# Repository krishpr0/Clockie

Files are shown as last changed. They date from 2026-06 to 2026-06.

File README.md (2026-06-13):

[tableConvert.com_3jk98l.md](https://github.com/user-attachments/files/28841670/tableConvert.com_3jk98l.md)
# CLOCKIE 

Clockie, It is an Smart Bedside clock, It is an overall clock with all the necessary daily life data.
This project contains multiple sensors such as ambient light sensor, humditiy sensor, temperature sensor, buzzer, etc, and it also supports upto 2 speakers, which can be configurered as right and left.

zine

## What is this Project?
Clockie is an bed side smart clock that has the ability to also be controlled via a web broswer, why?
This unlocks the ability to change what the display is showing, according to what the user likes and also gives the ability to show notifictions, calls, etc also being able to add alarams.

- It contains a big 3.2 TFT display.
-  Also allows the user to insert SD Card to play what they like and also act as storage.
- Display auto adjust the brightness according to the surronding due to the protect the eyes T_T at night (*relatable*)
- Has a Led Matrix on the back for kwoolll light shows and also acts as a background light.

## How do we use clockie?
hmm

- THere are overall 3 buttons and a rotarty encoder and also a skude switch :)

    - The buttons are A, B, C respectively from left to the right when the display is facing toward you.
    - The encoder is on the most right side.
 
    - The Button A, is for START.
    - The Button B, is for STOP.
    - The Button C, is for RESET.
 
    - The Encoder acts as the scroll wheel which u can use to raom around the menu.
    - If you press the Encoder shaft the built-in switch will get activated and selectes an option from the menu which you currently are hovering onto.

That's all to the controls all other models wil be visible on the display.

## AHA Reason for building this
I needed an good alarm clock really really baddly beacuse we have classes from 5:45 am and its very strict soo havee to wake up sharp and reach there at 5:30 am. I would always wake up late lolll so I wanted to make this hoping it could help me.

Well starting from my everyday life, a normal alarm has been a hassel and a mess. First of all if u look at it at night the display would be soo freaking bright that the eyes woule evaporate. and also the display would be either too small or too big, The traditional alarm clock has always been boring, simple, and not fun; We would say alarm clock is just an alarm clock why make it advance? butt nahh we can make it morea advance to make our life easier.

and so yeah  the main reaons I built it wwas that i could wake up early in da mornig and also will be able to save my already bad eyes. YESz, also the time i wake up i could clearly see the time, weather, is it raning or not?, the temperature, etc. also set my notes and reminders for completeing task or anyting.
and also one of the biggest rason was beacuse of my friend, she wanted one really bad but couldnt get her hands on one.

## CAD



## Circuit Diagram:




### PCB


## PCB 3D 




[tableConvert.com_3jk98l.md](https://github.com/user-attachments/files/28841686/tableConvert.com_3jk98l.md)
| # | Designator | Footprint | Description | LCSC # | Qty | Unit Price (USD) | Unit Price (NPR) | Amount (NPR) | Link |
|---|---|---|---|---|-----|---|---|---|---|
| 1 | R12 | R0603 | 180Ω Resistor | C94599 | 1 | $1.2381 | ₹165.29 | ₹165.29 | https://www.lcsc.com/product-detail/C94599.html |
| 2 | BUZZER1 | BUZ-SMD_4P | 2.7kHz Buzzer MLT-8530 | C94599 | 1 | $0.2080 | ₹27.77 | ₹27.77 | https://www.lcsc.com/product-detail/C94599.html |
| 3 | C2,C3,C12,C26 | C0603 | 1uF Cap CL10A105KB8NNNC | C15849 | 4 | $0.0109 | ₹1.46 | ₹5.82 | https://www.lcsc.com/product-detail/C15849.html |
| 4 | C6,C15,C17,C19  | C0603 | 10uF Cap CL10A106MA8NRNC | C96446 | 4 | $0.0362 | ₹4.83 | ₹19.33 | https://www.lcsc.com/product-detail/C96446.html |
| 5 | C8 | C0603 | 22uF Cap CL10A226MP8NUNE | C86295 | 1 | $0.0211 | ₹2.82 | ₹2.82 | https://www.lcsc.com/product-detail/C86295.html |
| 6 | C1,C4,C5,...C27 | C0603 | 100nF Cap CC0603KRX7R9BB104 | C14663 | 17  | $0.0107 | ₹1.43 | ₹24.28 | https://www.lcsc.com/product-detail/C14663.html |
| 7 | P1,P2,P3,P4 | CONN-TH_2P | 5mm Terminal Block WJ301V | C8475 | 4 | $0.0917 | ₹12.24 | ₹48.97 | https://www.lcsc.com/product-detail/C8475.html |
| 8 | U4 | ESOP-8 | MSMP2307DN-LF-Z | C49375228 | 1 | $1.1372 | ₹151.82 | ₹151.82 | https://www.lcsc.com/product-detail/C49375228.html |
| 9 | F1 | F1812 | Polyfuse 2.6A SMD1812P260TF | C438899 | 1 | $0.1178 | ₹15.73 | ₹15.73 | https://www.lcsc.com/product-detail/C438899.html |
| 10 | L1 | IND-SMD | 4.7uH Inductor CKCS5040 | C354606 | 1 | $0.0503 | ₹6.72 | ₹6.72 | https://www.lcsc.com/product-detail/C354606.html |
| 11 | LCD2 | LCD-TH | 3.5"" ILI9488 LCD HS32B01A  | C19632786 | 1 | $8.3381 | ₹1,113.14 | ₹1,113.14 | https://www.lcsc.com/product-detail/C19632786.html |
| 12 | LED3-LED132 | LED-SMD_4P | SK6812MINI-B RGB LED | C5183448  | 127 | $0.0937 | ₹12.51 | ₹1,588.64 | https://www.lcsc.com/product-detail/C5183448.html  |
| 13 | LED2 | LED-SMD_4P | VEML7700-TR Light Sensor | C504893 | 1 | $0.7128 | ₹95.16 | ₹95.16 | https://www.lcsc.com/product-detail/C504893.html |
| 14 | LED1 | LED-SMD_L1.0 | NCD0402R1 Red LED | C130719 | 1 | $0.0386 | ₹5.15 | ₹5.15 | https://www.lcsc.com/product-detail/C130719.html |
| 15 | U1 | MIC-SMD_6P | ICS-43434 MEMS Mic | C5656610  | 1 | $6.5631 | ₹876.17 | ₹876.17 | https://www.lcsc.com/product-detail/C5656610.html  |
| 16 | U8 | QFN-24 | BQ25895RTWR USB-C Charger | C80200 | 1 | $2.0396 | ₹272.29 | ₹272.29 | https://www.lcsc.com/product-detail/C80200.html |
| 17 | R22 | R0402 | 33Ω Resistor RC0402FR | C138002 | 1 | $0.1000 | ₹13.35 | ₹13.35 | https://www.lcsc.com/product-detail/C138002.html |
| 18 | R11 | R0603 | 1kΩ Resistor RC0603FR | C22548 | 1 | $0.1800 | ₹24.03 | ₹24.03 | https://www.lcsc.com/product-detail/C22548.html |
| 19 | R24,R25 | R0603 | 2.2kΩ Resistor 0603WAF2201  | C4190 | 2 | $0.1500 | ₹20.02 | ₹40.05 | https://www.lcsc.com/product-detail/C4190.html |
| 20 | R2,R3 | R0603 | 5.1kΩ Resistor 0603WAF5101  | C23186 | 2 | $0.1600 | ₹21.36 | ₹42.72 | https://www.lcsc.com/product-detail/C23186.html |
| 21 | R8,R9,R10 | R0603 | 10kΩ Resistor 0603WAF1002 | C25804 | 3 | $0.1100 | ₹14.69 | ₹44.05 | https://www.lcsc.com/product-detail/C25804.html |
| 22 | R1,R13-R20,R26  | R0603 | 10kΩ Resistor RC0603FR | C98220 | 9 | $0.1800 | ₹24.03 | ₹216.27 | https://www.lcsc.com/product-detail/C98220.html |
| 23 | R6,R23 | R0603 | 100kΩ Resistor 0603WAF1003  | C25803 | 2 | $0.1800 | ₹24.03 | ₹48.06 | https://www.lcsc.com/product-detail/C25803.html |
| 24 | R5 | R0603 | 200kΩ Resistor 0603WAF2003  | C25811 | 1 | $0.1700 | ₹22.70 | ₹22.70 | https://www.lcsc.com/product-detail/C25811.html |
| 25 | R21 | R1206 | 100Ω Resistor CR1206F100R | C245445 | 1 | $0.0057 | ₹0.76 | ₹0.76 | https://www.lcsc.com/product-detail/C245445.html |
| 26 | S1 | SENSOR-SMD | HDC1080DMBR Temp/Humidity | C82227 | 1 | $1.4400 | ₹192.24 | ₹192.24 | https://www.lcsc.com/product-detail/C82227.html |
| 27 | U7 | SOIC-16 | DS3231SN RTC | C9866 | 1 | $5.3806 | ₹718.31 | ₹718.31 | https://www.lcsc.com/product-detail/C9866.html |
| 28 | SW5 | SW-SMD | SSAG230400 Rotary Encoder | C255506 | 1 | $0.3076 | ₹41.06 | ₹41.06 | https://www.lcsc.com/product-detail/C255506.html |
| 29 | SW2,SW3,SW4 | SW-TH | 1-1825027-4 Tactile Switch  | C2928195  | 3 | $0.1499 | ₹20.01 | ₹60.03 | https://www.lcsc.com/product-detail/C2928195.html  |
| 30 | U13 | SW-TH_CTR | ED0890DM Knob w/ Switch | C18213470 | 1 | $3.8268 | ₹510.88 | ₹510.88 | https://www.lcsc.com/product-detail/C18213470.html |
| 31 | CARD1 | TF-SMD | TF-01A MicroSD Socket | C91145 | 1 | $0.1922 | ₹25.66 | ₹25.66 | https://www.lcsc.com/product-detail/C91145.html |
| 32 | USB1 | USB-C-SMD | TYPE-C 16PIN 2MD Connector  | C2765186  | 1 | $0.0705 | ₹9.41 | ₹9.41 | https://www.lcsc.com/product-detail/C2765186.html  |
| 33 | U2 | VSSOP-10 | DRV2605LDGSR Haptic Driver  | C527464 | 1 | $1.2010 | ₹160.33 | ₹160.33 | https://www.lcsc.com/product-detail/C527464.html |
| 34 | U14 | MODULE | ESP32-S3-WROOM-1U-N16 | C2980298  | 1 | $5.6146 | ₹749.55 | ₹749.55 | https://www.lcsc.com/product-detail/C2980298.html  |
| 35 | U6,U12 | WLP-9 | MAX98357AEWL+T I2S Amp | C2682619  | 2 | $0.4656 | ₹62.16 | ₹124.32 | https://www.lcsc.com/product-detail/C2682619.html  |
| 36 | U3 | WSOF-6 | BH1750FVI-TR Lux Sensor | C78960 | 1 | $0.9329 | ₹124.54 | ₹124.54 | https://www.lcsc.com/product-detail/C78960.html |
| TOTAL | | | | | 203 | | | ₹7,587.41 | |

## How to Build


### What you need
- Soldering iron (fine tip recommended)
- Solder wire 
- Flux
- Multimeter
- USB-C cable

### Assembly order
1. Solder all SMD passives first (resistors, capacitors)
2. Solder ICs — BQ25895, MP2307, DS3231, HDC1080, BH1750, DRV2605, MAX98357 ×2
3. Solder ESP32-S3-WROOM-1U module
4. Solder USB-C connector and test 5V rail with multimeter before connecting anything else
5. Solder connectors — terminal blocks, SD card slot
6. Solder through-hole components — buttons, encoder
7. Connect LiPo battery via JST connector
8. Connect display via HDR-1X9 header
9. Solder SK6812 LED matrix on back side
10. Flash firmware via USB-C using PlatformIO
11. Open Serial Monitor — verify WiFi connects and sensors respond
12. Access web UI at the IP shown in Serial Monitor

### Firmware setup
- Install PlatformIO in VS Code
- Clone this repo
- Edit `firmware/src/config.h` — add your WiFi SSID, password, and OpenWeatherMap API key
- Run `pio run --target upload`

## GPIO Pinout
| GPIO | Function |
|---|---|
| IO4  | Reset button |
| IO5  | Encoder SW |
| IO6  | Encoder A |
| IO7  | Encoder B |
| IO8  | I2C SDA |
| IO9  | I2C SCL |
| IO10 | TFT CS |
| IO11 | SPI MOSI |
| IO12 | SPI SCK |
| IO13 | SPI MISO |
| IO14 | TFT RS/DC |
| IO15 | I2S LRCLK |
| IO16 | I2S BCLK |
| IO17 | I2S DIN |
| IO18 | Buzzer |
| IO19 | USB D- |
| IO20 | USB D+ |
| IO35 | LED matrix data |
| IO36 | Haptic trigger |
| IO37 | HOME button |
| IO38 | BACK button |
| IO39 | EXTRA button |
| IO45 | Mic SD |
| IO46 | SD card CS |
| IO47 | Mic SCK |
| IO48 | Mic WS |

# Feature
- Wifi & BLE capabilities
- 3 buttons & enconder
- 3.2 inch TFT display
- ESP32-S3**
- Temperature & Humiditiy sensor
- Ambient light sensor
- Haptic feedback
- Supports 2 speakers
- LED Matrix
- RTC
- BMS and charger
- Prayer times (Aladhan API)
- Google Calendar integration
- Pomodoro timer
- Web browser control
- Microphone
- MicroSD audio playback
- Auto brightness (BH1750 ambient light sensor)
- USB-C charging
- Backup battery (LiPo)

# Hardware
| Component | Part |
|---|---|
| MCU | ESP32-S3-WROOM-1U-N16 |
| Display | 3.2" ST7789 TFT HS32B01A |
| Charger IC | BQ25895RTWR |
| Buck converter | MSMP2307DN |
| Audio amp | MAX98357AEWL+T ×2 (stereo) |
| RTC | DS3231SN |
| Temp/Humidity | HDC1080DMBR |
| Light sensor | BH1750FVI-TR |
| Haptic driver | DRV2605LDGSR |
| Microphone | ICS-43434 |
| LED matrix | SK6812MINI-B ×127 |
| Encoder | EC11E18244A5 |
| Buttons | 1-1825027-4 ×3 |
| MicroSD | TF-01A |
| USB-C | TYPE-C 16PIN 2MD |
| PCB | Custom 2-layer JLCPCB |
| Case | 3D printed PETG |

## Web Interface
Once powered on and connected to WiFi, open a browser on any device 
on the same network and go to the IP address shown on the display.

From the web interface you can:
- Add and remove alarms
- Control LED matrix mode and color
- Start/stop Pomodoro timer
- Adjust display brightness
- View current weather and prayer times

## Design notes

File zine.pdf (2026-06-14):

the smart clock. cclloocckkiiee,,

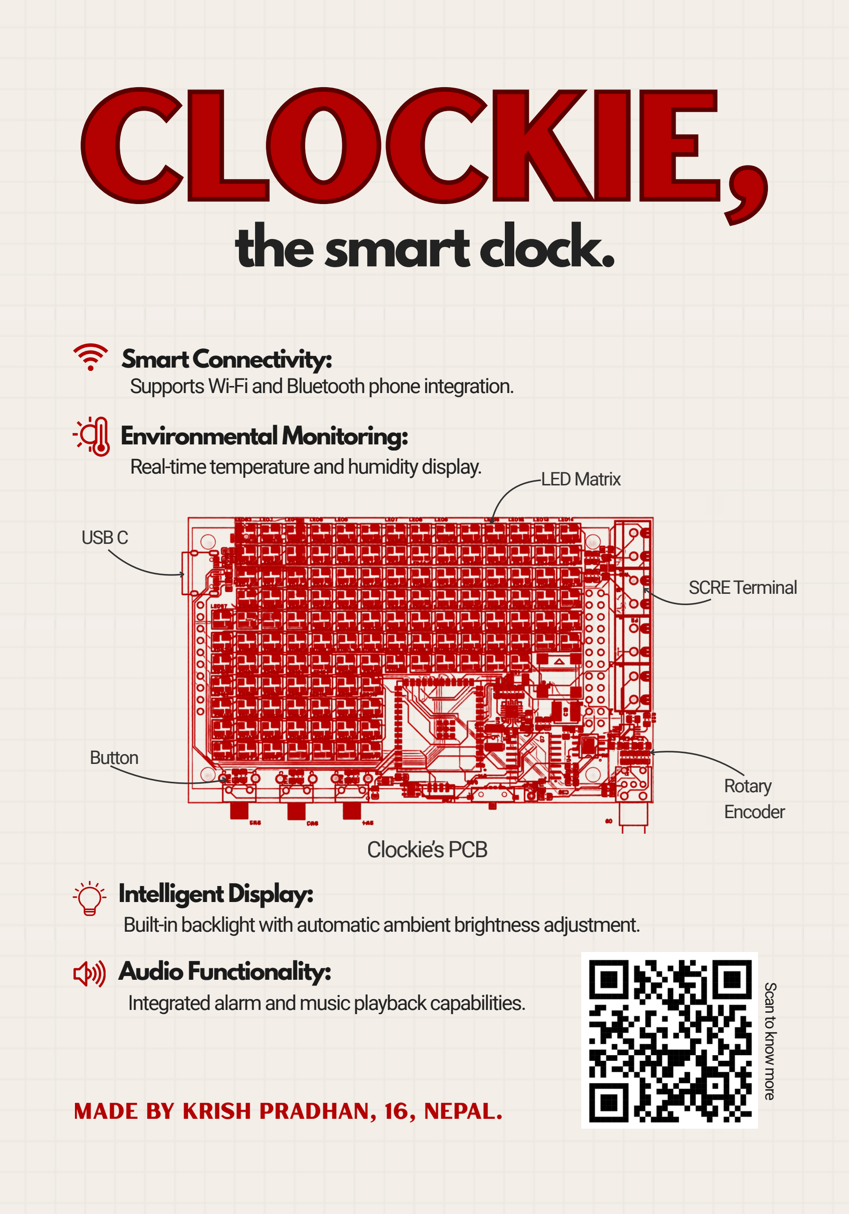
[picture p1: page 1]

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
Clockie’sPCB

SupportsWi-Fi andBluetoothphone integration.

SmartConnectivity:

Environmental Monitoring:

Intelligent Display:

AudioFunctionality:

Real-time temperature andhumiditydisplay.

Built-inbacklightwith automatic ambientbrightness adjustment.

Integratedalarmandmusicplayback capabilities.

Made by Krish Pradhan, 16, Nepal.

USBC

LEDMatrix

SCRETerminal

Rotary
Encoder

Button

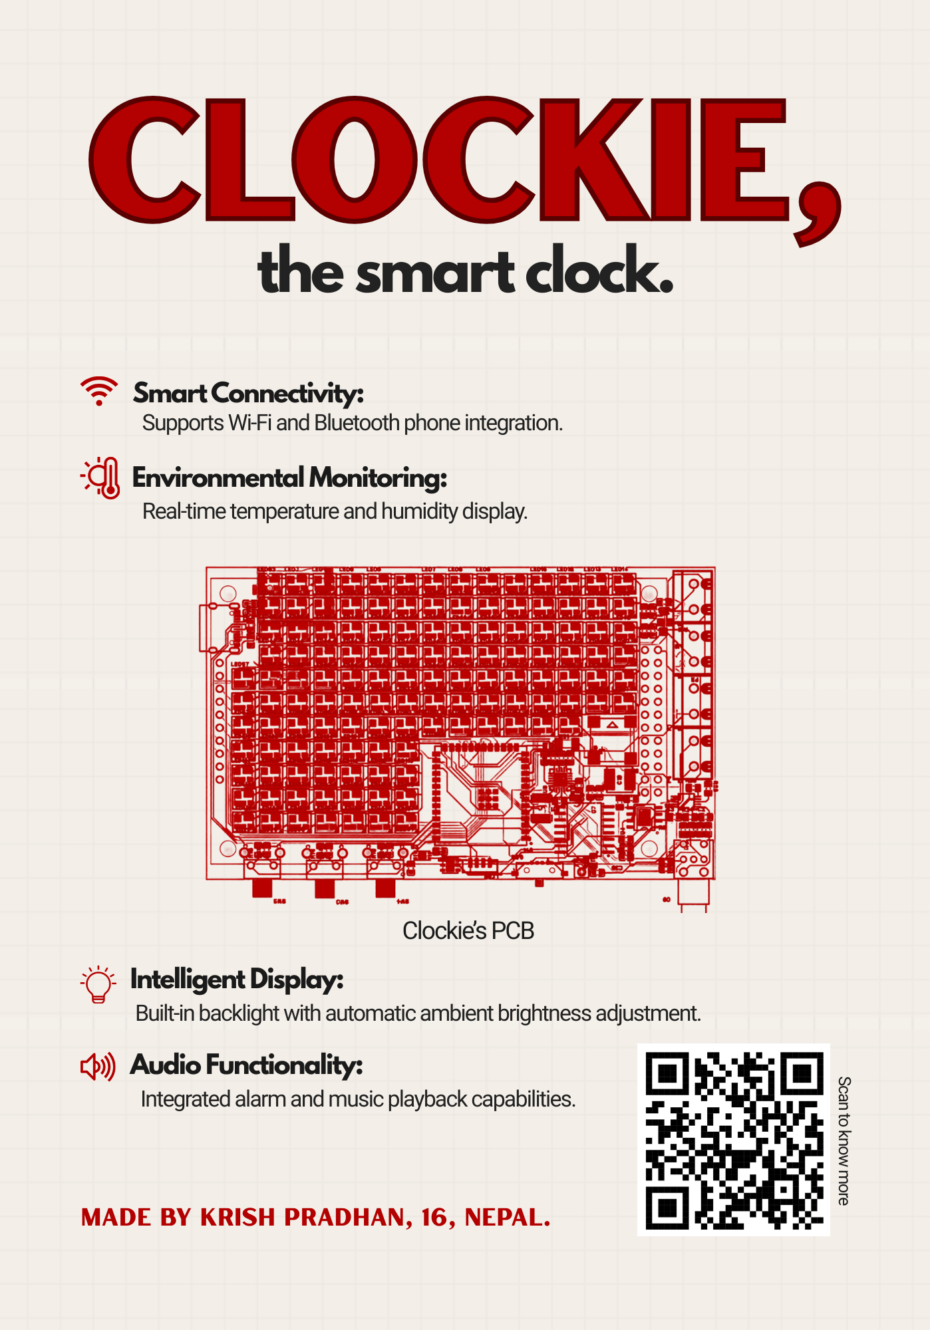
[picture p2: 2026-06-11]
zine.png

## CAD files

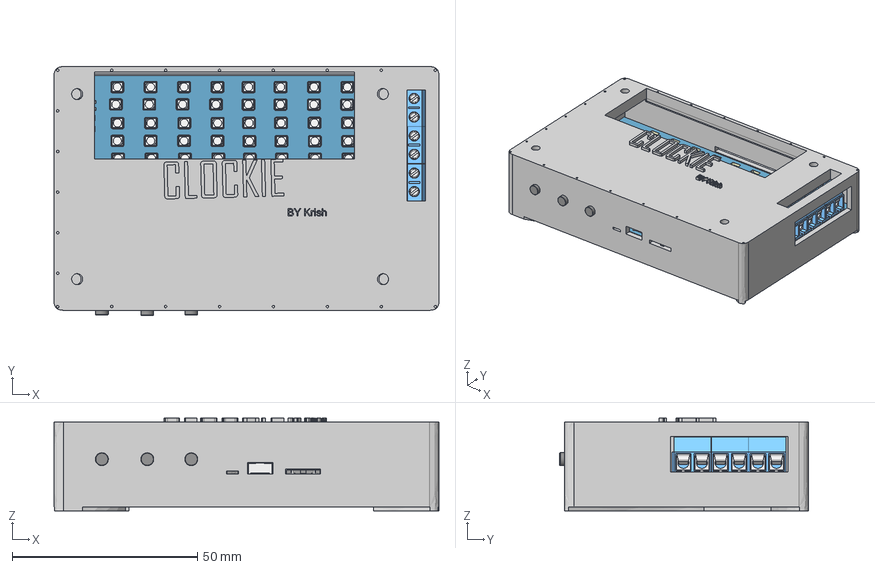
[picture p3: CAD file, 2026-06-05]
CAD/Clockie.step
104.0 x 67.2 x 25.0 mm
Board~MeGX
TopCopper~MeGX
BottomCopper~MeGX
TopFpcStiffener~MeGX
BottomFpcStiffener~MeGX
C0603~C0603_L1.6-W0.8-H0.8~MeGX x 21
CONN-TH_2P-P5.00_WJ301V-5.00-2P~CONN-TH_2P-P5.00_WJ301V-5.00-2P~MeGX x 3
R0603~R0603~MeGX x 18
F1812~F1812_L4.5-W3.2-H1.0~MeGX
LED0402-RD_YELLOW~LED0402-RD_YELLOW~MeGX
IND-SMD_L5.0-W5.0~IND-SMD_L5.0-W5.0-H2.1~MeGX
QFN-24_L4.0-W4.0-P0.50-TL-EP2.7~QFN-24_L4.0-W4.0-P0.50-TL-EP2.7~MeGX
SW-TH_1-1825027-4~SW-TH_1-1825027-4~MeGX x 3
ESOP-8_L4.9-W3.9-P1.27-LS6.0-BL-EP~ESOP-8_L4.9-W3.9-H1.6-LS6.0-P1.27~ MeGX
BUZ-SMD_4P-L8.5-W8.5-P8.50-BR~BUZ-SMD_4P-L8.5-W8.5-H3.0~MeGX
SW-SMD_SSAG230400~SW-SMD_SSAG230400~MeGX
USB-C-SMD_TYPE-C-16PIN-2MD-073~USB-C-SMD_TYPE-C-6PIN-2MD-073~MeGX
LED-SMD_4P-L6.8-W2.4_VEML7700-TR~LED-SMD_4P-L6.8-W2.4_VEML7700-TR~MeG X
SOIC-16_L10.3-W7.5-P1.27-LS10.3-BL~SOIC-16_L10.3-W7.5-H2.7-LS10.3-P1. 27~MeGX
LED-SMD_4P-L3.2-W2.8-LS5.9_SK6812MINI-E~LED-SMD_4P-L3.2-W2.8-LS5.9_SK 6812MINI-E~MeGX x 40
SENSOR-SMD_HDC1080DMBR~SENSOR-SMD_L3.0-W3.0-H0.8-P1.0~MeGX
WLP-9_L1.4-W1.3-P0.40-R3-C3-BR~WLP-9_L1.4-W1.3-P0.40-R3-C3-BR~MeGX x 2
WIRELM-SMD_ESP32-S3-WROOM-1U~WIRELM-SMD_ESP32-S3-WROOM-1U~MeGX
LCD-TH_L89.4-W56.0_HS32B01A~LCD-TH_L89.4-W56.0_HS32B01A~MeGX

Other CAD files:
CAD/Clockie.3mf
CAD/Clockie.f3z

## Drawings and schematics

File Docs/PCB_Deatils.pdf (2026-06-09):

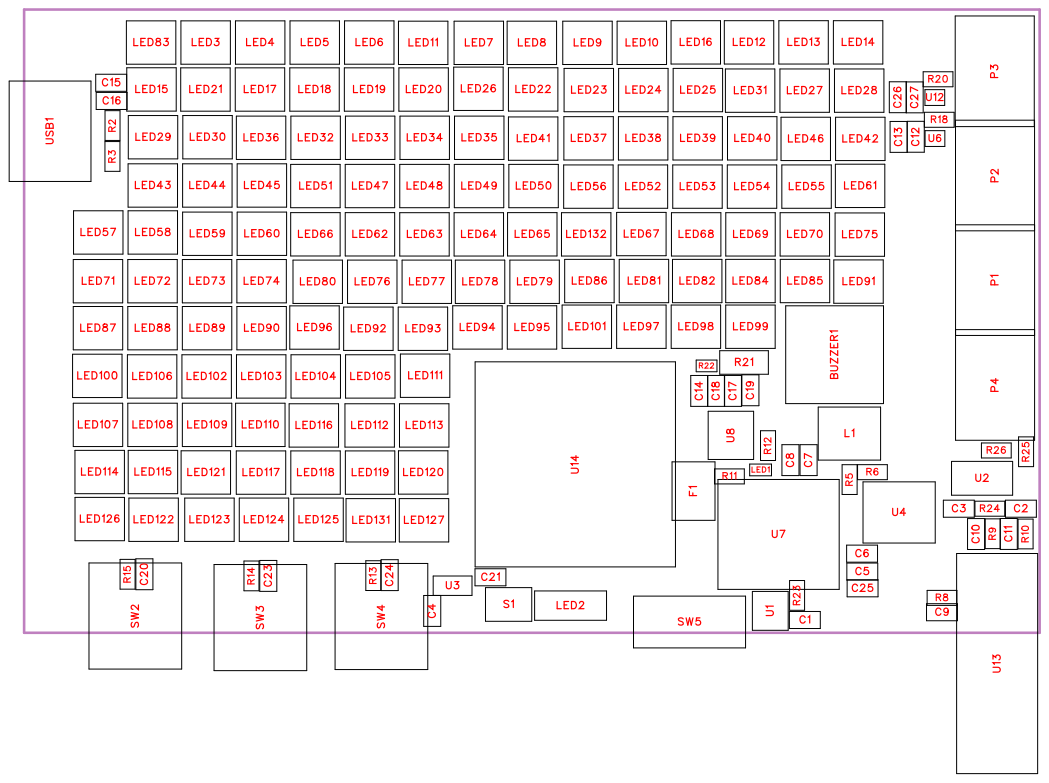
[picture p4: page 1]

LED83 | LED3 | LED4 | LED5 | LED6 | LED11 | LED7 | LED8 | LED9 | LED10 | LED16 | LED12 | LED13 | LED14

C15 | LED15 | LED21 | LED17 | LED18 | LED19 | LED20 | LED26 | LED22 | LED23 | LED24 | LED25 | LED31 | LED27 | LED28 | R20
C16 | | | | | | | | | | | | | | | | U12
LED29 | | LED30 | LED36 | LED32 | LED33 | LED34 | LED35 | LED41 | LED37 | LED38 | LED39 | LED40 | LED46 | LED42 | | R18

LED43 | LED44 | LED45 | LED51 | LED47 | LED48 | LED49 | LED50 | LED56 | LED52 | LED53 | LED54 | LED55 | LED61

LED57 | LED58 | LED59 | LED60 | LED66 | LED62 | LED63 | LED64 | LED65 | LED132 | LED67 | LED68 | LED69 | LED70 | LED75

LED71 | LED72 | LED73 | LED74 | LED80 | LED76 | LED77 | LED78 | LED79 | LED86 | LED81 | LED82 | LED84 | LED85 | LED91

LED87 | LED88 | LED89 | LED90 | LED96 | LED92 | LED93 | LED94 | LED95 | LED101 | LED97 | LED98 | LED99

LED100 | LED106 | LED102 | LED103 | LED104 | LED105 | LED111 | | | R22 | R21

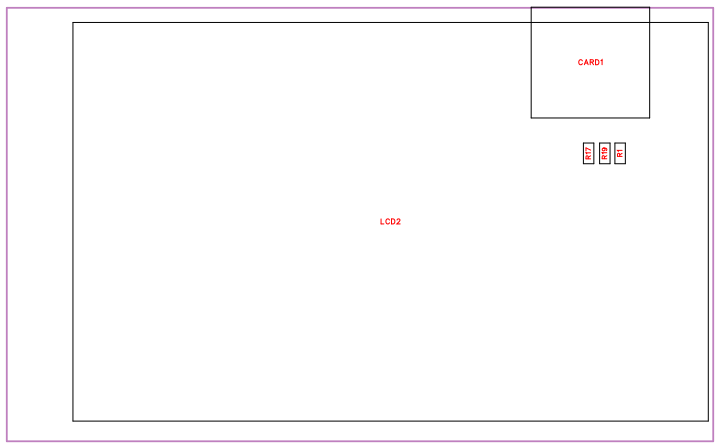
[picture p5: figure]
CARD1; LCD2

No. | Quantity | Designator | Footprint | Value | Manufacturer Part | Supplier Part | LCSC Price
1 | 1 | BUZZER1 | BUZ-SMD_4 P-L8.5-W8.5-P8.50-BR | 2.7kHz | MLT-8530 | C94599
2 | 17 | C1,C4,C5,C7,C9,C10,C11, C13,C14,C16,C18,C20,C21 ,C23,C24,C25,C27 | C0603 | 100nF | CC0603KRX 7R9BB104 | C14663
3 | 4 | C2,C3,C12,C26 | C0603 | 1uF | CL10A105KB 8NNNC | C15849
4 | 4 | C6,C15,C17,C19 | C0603 | 10uF | CL10A106M A8NRNC | C96446
5 | 1 | C8 | C0603 | 22uF | CL10A226M P8NUNE | C86295
6 | 1 | CARD1 | TF-SMD_TF-01A | | TF-01A | C91145
7 | 1 | F1 | F1812 | | SMD1812P2 60TF/16 | C438899
8 | 1 | L1 | IND-SMD_L5 .0-W5.0 | 4.7uH | CKCS5040-4 .7uH/M | C354606
9 | 1 | LCD2 | LCD-TH_L89 .4-W56.0_HS 32B01A | | HS32B01A | C19632786
10 | 1 | LED1 | LED-SMD_L 1.0-W0.5_FC -F1005UGK | | NCD0402R1 | C130719
11 | 1 | LED2 | LED-SMD_4 P-L6.8-W2.4 _VEML7700-TR | | VEML7700-T R | C504893

12 | 127 | LED3,LED4,LED5,LED6,LE D7,LED8,LED9,LED10,LED 11,LED12,LED13,LED14,LE D15,LED16,LED17,LED18, LED19,LED20,LED21,LED2 2,LED23,LED24,LED25,LE D26,LED27,LED28,LED29, LED30,LED31,LED32,LED3 3,LED34,LED35,LED36,LE D37,LED38,LED39,LED40, LED41,LED42,LED43,LED4 4,LED45,LED46,LED47,LE D48,LED49,LED50,LED51, LED52,LED53,LED54,LED5 5,LED56,LED57,LED58,LE D59,LED60,LED61,LED62, LED63,LED64,LED65,LED6 6,LED67,LED68,LED69,LE D70,LED71,LED72,LED73, LED74,LED75,LED76,LED7 7,LED78,LED79,LED80,LE D81,LED82,LED83,LED84, LED85,LED86,LED87,LED8 8,LED89,LED90,LED91,LE D92,LED93,LED94,LED95, LED96,LED97,LED98,LED9 9,LED100,LED101,LED102, LED103,LED104,LED105,L ED106,LED107,LED108,LE D109,LED110,LED111,LED 112,LED113,LED114,LED1 15,LED116,LED117,LED11 8,LED119,LED120,LED121, LED122,LED123,LED124,L ED125,LED126,LED127,LE D131,LED132

LED-SMD_4
P-L3.5-W3.5-
R-SK6812MI
NI

SK6812MINI-B-012

C5183448

13 | 4 | P1,P2,P3,P4 | CONN-TH_2 P-P5.00_WJ 301V-5.00-2 P | | WJ301V-5.0-02P-12-00A | C8475
14 | 9 | R1,R13,R14,R15,R17,R18, R19,R20,R26 | R0603 | 10k | RC0603FR-0 710KL | C98220
15 | 2 | R2,R3 | R0603 | 5.1k | 0603WAF51 01T5E | C23186
16 | 1 | R5 | R0603 | 200k | 0603WAF20 03T5E | C25811
17 | 2 | R6,R23 | R0603 | 100k | 0603WAF10 03T5E | C25803
18 | 3 | R8,R9,R10 | R0603 | 10k | 0603WAF10 02T5E | C25804
19 | 1 | R11 | R0603 | 1k | RC0603FR-0 71KL | C22548
20 | 1 | R12 | R0603 | 180 | | | 0.1759
21 | 1 | R21 | R1206 | 100 | CR1206F100 RP05Z | C245445

22 | 1 | R22 | R0402 | 33 | RC0402FR-0 733RL | C138002
23 | 2 | R24,R25 | R0603 | 2.2k | 0603WAF22 01T5E | C4190
24 | 1 | S1 | SENSOR-SM D_HDC1080 DMBR | | HDC1080DM BR | C82227
25 | 3 | SW2,SW3,SW4 | SW-TH_1-18 25027-4 | | 1-1825027-4 | C2928195
26 | 1 | SW5 | SW-SMD_SS AG230400 | | SSAG23040 0 | C255506
27 | 1 | U1 | MIC-SMD_6 P-L3.5-W2.7-P0.90-BL | | ICS-43434 | C5656610
28 | 1 | U2 | VSSOP-10_L 3.0-W3.0-P0. 50-LS4.9-BL | | DRV2605LD GSR | C527464
29 | 1 | U3 | WSOF-6_L2. 6-W1.6-P0.5 0-TL-EP | | BH1750FVI-TR | C78960
30 | 1 | U4 | ESOP-8_L4. 9-W3.9-P1.2 7-LS6.0-BL-E P | | MSMP2307D N-LF-Z | C49375228
31 | 2 | U6,U12 | WLP-9_L1.4-W1.3-P0.40-R3-C3-BR | | MAX98357A EWL+T | C2682619
32 | 1 | U7 | SOIC-16_L1 0.3-W7.5-P1. 27-LS10.3-B L | | DS3231SN# T&R | C9866
33 | 1 | U8 | QFN-24_L4.0 -W4.0-P0.50-TL-EP2.7 | | BQ25895RT WR | C80200
34 | 1 | U13 | SW-TH_CTR _ED0890DM-FE13.8S5.8-C10-2030 | | ED0890DM-FE13.8S5.8-C10-2030 | C18213470
35 | 1 | U14 | WIRELM-SM D_ESP32-S3 -WROOM-1U | 2.4GHz | ESP32-S3-W ROOM-1U-N 16 | C2980298
36 | 1 | USB1 | USB-C-SMD _TYPE-C-16 PIN-2MD-07 3 | | TYPE-C 16PIN 2MD(073) | C2765186

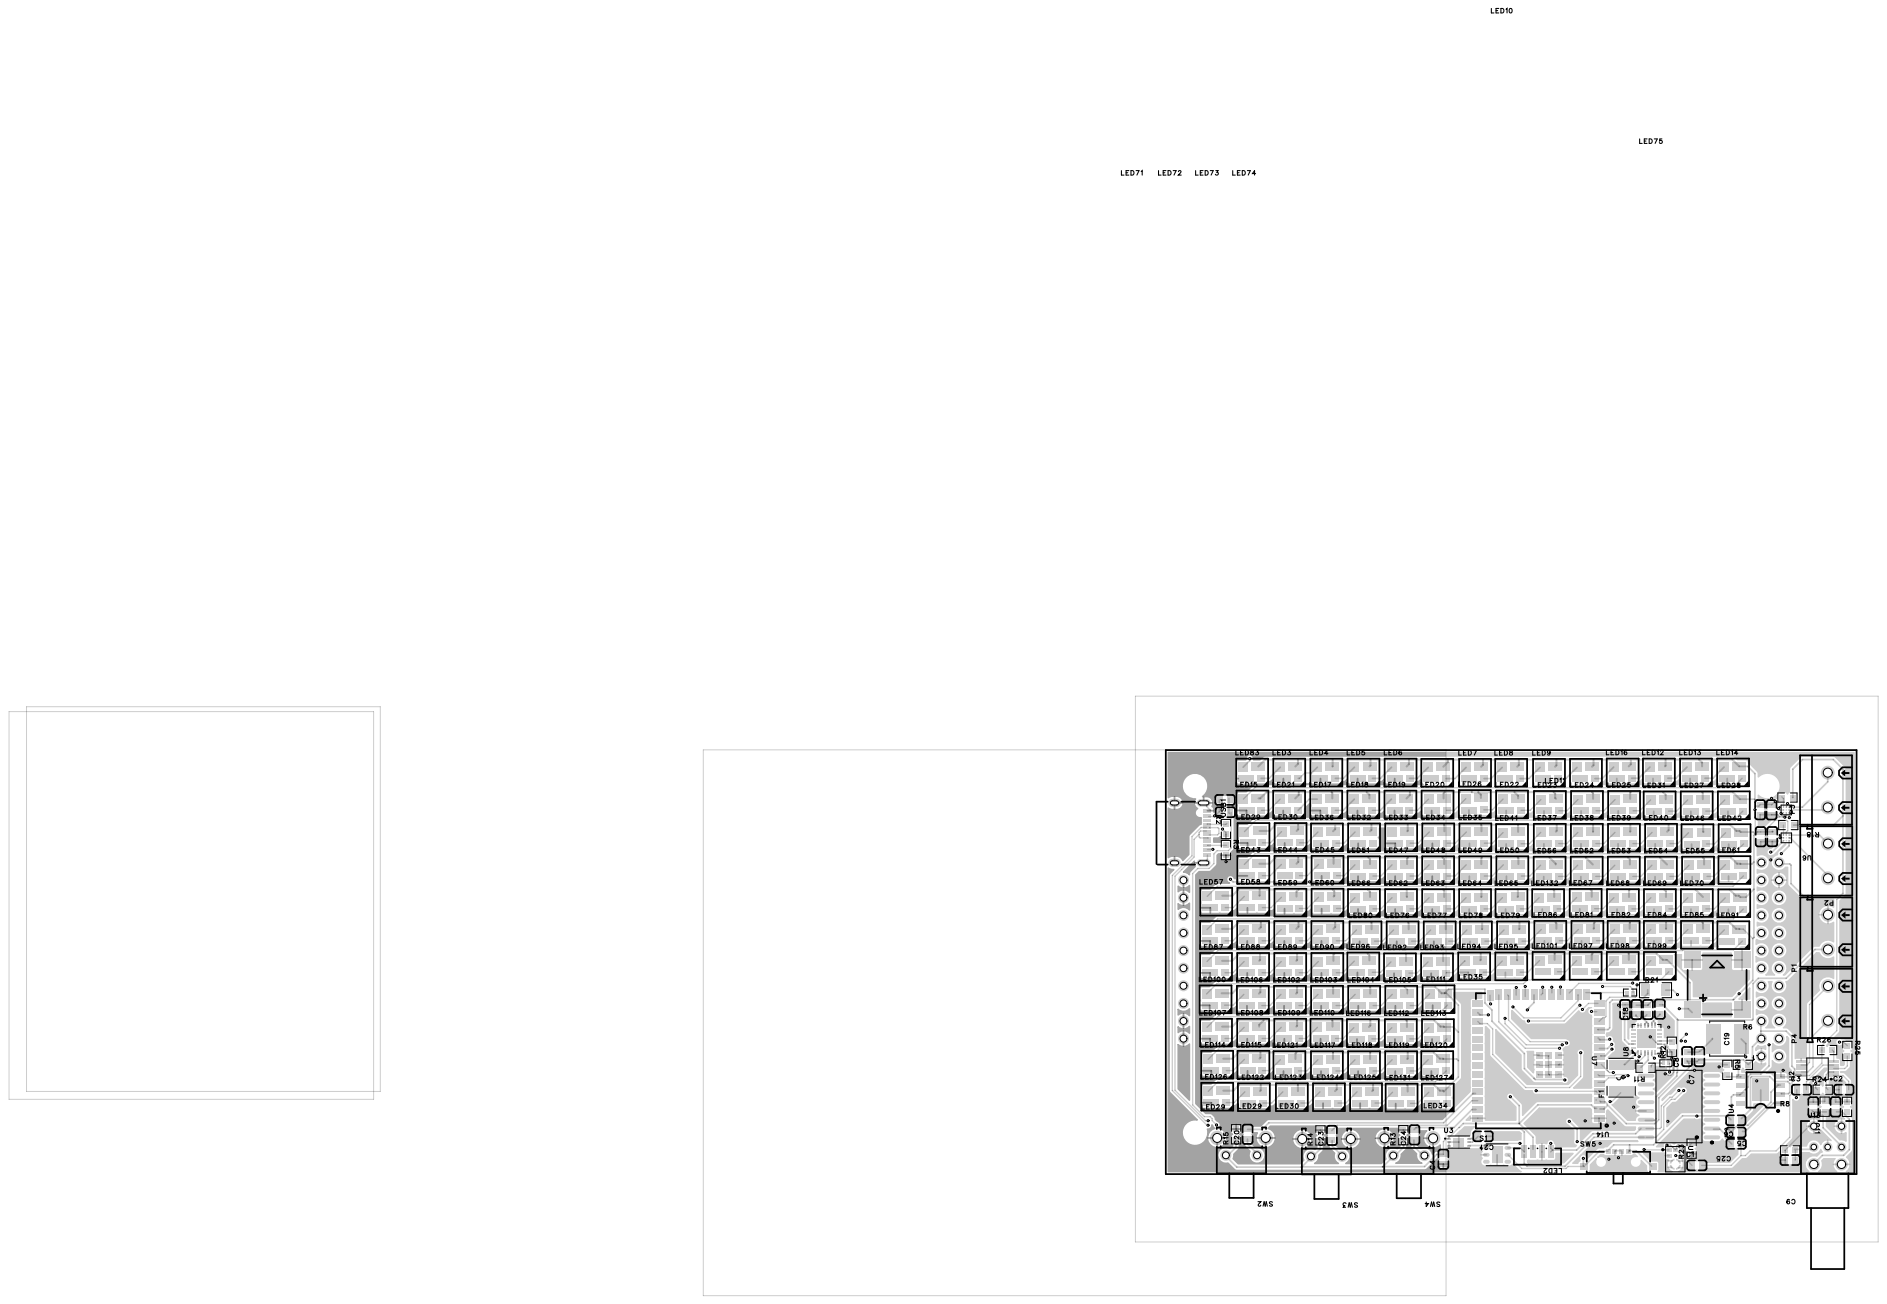
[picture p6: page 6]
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

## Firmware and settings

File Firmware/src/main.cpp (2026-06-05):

#include <Arduino.h>
#include <Wire.h>
#include <TFT_eSPI.h>
#include <lvgl.h>
#include "config.h"
#include "display.h"
#include "../CLOCKKIE/LEDS.h"
#include "../CLOCKKIE/alarm.h"
#include "input.h"
#include "alarm.h"
#include "pomodoro.h"
#include "ui.h"
#include "webserver.h"


TFT_eSPI tft = TFT_eSPI();


TaskHandle_t taskNetwork;
TaskHandle_t taskLEDs;



uint32_t lastUIUpdate = 0;
uint32_t lastNTP = 0;
uint32_t lastWeather = 0;
uint32_t lastPrayer = 0;
uint32_t lastCalendar = 0;
uint32_t lastBLCheck = 0;
uint32_t lastAlarmCheck = 0;
int lastMinute = -1;




void network_task (void *param) {
    for (;;) {

        //EVERY NTP 5 SEC
        if (millis() - lastNTP > 300000UL) {
            ntp_update();
            lastNTP = millis();
        }



        //Weather every 10 mins
        if (millis() - lastWeather > 600000UL) {
            fetch_weather();
            lastWeather = millis();
        }


        //Prayers every 6 hrs
        if (millis() - lastPrayer > 21600000UL) {
            fetch_prayers();
            lastPrayer = millis();
        }


        //calendar every 5 mins
        if (millis() - lastCalendar > 300000UL) {
            fetch_calendar();
            lastCalendar = millis();
        }
        vTaskDelay(1000 / portTICK_PERIOD_MS);
    }
}





void led_task(void *param) {
    for (;;) {
        leds_update();
        vTaskDelay(20 / portTICK_PERIOD_MS);
    }
}



void auto_brightnesss() {
    int h = get_hour();
    if (h >= NIGHT_HOUR || h < MORNING_HOUR) {
        set_brightness(BL_NIGHT);
        leds_set_brightness(20);
    } else {
        set_brightness(BL_DAY);
        leds_set_brightness(LED_BRIGHTNESS);
    }
}



void setup() {
    Serial.being(115200);
    Serial.println("Clockie bootin...");


    //I2C
    Wire.being(I2C_SDA, I2C_SCL);


    //Display + LVGL
    display_init();



    //show boot screeen
    lv_obj_t *boot = lv_obj_create(lv_scr_act());
    lv_obj_set_size(boot, SCREEN_W, SCREEN_H);
    lv_obj_set_style_bg_color(boot, lv_color_hex(0x0a0a0a), 0);
    lv_obj_set_style_border_width(boot, 0, 0);
    lv_obj_t *bootLabel = lv_label_create(boot);
    lv_label_set_text(bootLabel, "CLOCKIE");
    lv_obj_set_style_text_font(bootLabel, &lv_font_montserrat_48, 0);
    lv_obj_set_style_text_color(bootLabel, lv_color_hex(0x6366f1), 0);
    lv_obj_align(bootLabel, LV_ALIGN_CENTER, 0, -20);
    lv_obj_t *bootSub = lv_label_create(boot);
    lv_label_set_text(bootSub, "BY KRISH");
    lv_obj_set_style_text_font(bootSub, &lv_font_montserrat_16, 0);
    lv_obj_set_style_text_color(bootSub, lv_color_hex(0x444444), 0);
    lv_obj_align(bootSub, LV_ALIGN_CENTER, 0, 30);
    lv_timer_handler();
    delay(1500);



    //LEDS
    leds_int();
    leds_set_mode(LED_BREATHE, CRGB::Purple);


    //Input
    input_init();


    //alarm
    alarm_init();


    //wifi
    wifi_connect();


    if (wifi_connected) {
        ntp_update();
        fetch_weather();
        fetch_prayers();
        refresh_gcal_token();
        fetch_calendar();
        webserver_init();
        lastNTP = millis();
        lastWeather = millis();
        lastPrayer = millis();
        lastCalendar = millis();
    }


    ui_init();


    leds_set_mode(LED_RAINBOW);


    xTaskCreatePinnedToCore(network_task, "netwwork", 8192, NULL, 1, &taskNetwork, 0);
    xTaskCreatePinnedToCore(led_task, "leds", 4096, NULL, 1, &taskLEDs, 0);

    Serial.println("CLockie readyu!");
    Serial.printf("Web UI: https://%s\n", WiFi.local().toString().c_str());
}



void loop() {
    lv_timer_handler();


    int delta = input_get_delta();
    bool clicked = input_enc_clicked();
    bool home = input_home_pressed();
    bool back = input_back_pressed();
    bool extra = input_extra_pressed();


    if (extra) {
        static int ledModeIdx = 1;
        ledModeIdx = (ledModeIdx + 1) % 6;
        leds_set_mode((LedMode)ledModeIdx);
    }


    ui_handle_input(delta, clicked, home, back);


    if (millis() - lastUIupdate > 500) {
        ui_update();
        lastUIupdate = millis();
    }



    if (millis() - lastBLCheck > 600000UL) {
        ui_update();
        lastUIUpdate = millis();
    }



    if (millis() - lastAlarmCheck > 1000UL) {
        int h = get_hour();
        int m = get_minute();
        if (alarm_check(h, m)) {
            leds_set_mode(LED_ALRAM);
        }
        alarm_update();


        if (m != lastMinute) {
            alarm_reset_triggers(h, m);
            lastMinute = m;
        }
        lastAlarmCheck = millis();
    }



    if (pom_update()) {
        buzzer_beep(3);
        leds_set_mode(pomState == POM_WORK ? LED_RAINBOW : LED_BREATHE);
    }


    if (wifi_connected) webserver_handle();
    delay(5);
}

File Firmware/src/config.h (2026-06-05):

#pragma once


//Display
#define TFT_MOSI_PIN 13
#define TFT_SCK_PIN 12
#define TFT_CS_PIN 11
#define TFT_DC_PIN 10
#define TFT_RST_PIN 16
#define TFT_BL_PIN 3


//I2C
#define I2C_SDA 17
#define I2C_SCL 18


//Encoder
#define ENC_A 36
#define ENC_B 35
#define ENC_SW 37


//Buttons
#define BTN_HOME 4
#define BTN_BACK 6
#define BTN_EXTRA 15


// AMPs (MAX98357A)
#define I2S_BCLK 26
#define I2S_LRCLK 27
#define I2S_DOUT 25


//Mic (ICS-43434)
#define MIC_SCK 47
#define MIC_WS 48
#define MIC_SD 45


//LED (SK6812MINI-E) 10*10 grid
#define LED_DATA_PIN 42
#define LED_COUNT 100
#define LED_BRIGHTNESS 64 //its the 25% default


//Buzzwer
#define BUZZER_PIN 7


//SD_CARD
#define SD_CS_PIN 5
#define BQ25895_INT_PIN 38
#define USB_DN_PIN 19
#define USB_DP_PIN 20



//WIFI
#define WIFI_SSID "...."
#define WIFI_PASS "...."


//APIs
#define OPENWEATHER_API "...."
#define WEATHER_CITY "Kathmandu"
#define WEATHER_COUNTRY "Nepal"
#define WEATHER_UNIT "Metrics"


//Google Calendar Auth
#define GCAL_CLIENT_ID "..." //replace with your client id
#define GCAL_CLIENT_SECRET "..."
#define GCAL_REFRESH_TOKEN "..." 


//Time
#define NTP_SERVER  "https://www.ntppool.org/en/"
#define NTP_OFFSET 20700 // Nepal UTC+5:45 in sec make sure to replace with ur
#define  TIME_24H true


//POMODORO TIMER (all in minutes)
#define POMODORO_WORK 25 
#define POMODORO_SHORT 5 //this is the short break 
#define POMODORO_LONG 15// this is the long break


//Display Brightness
#define BL_DAY 200
#define BL_NIGHT 30
#define NIGHT_HOUR 22 // 10pm in 12 hr clock format
#define MORNING_HOUR 6 //am


//Dimension
#define SCREEN_H 320
#define SCREEN_W 240




#define PRAYER_LAT .....
#define PRAYER_LON .....
#define PRAYER_METHOD 1

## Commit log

2026-06-05 CAD and Firmware files
2026-06-09 all remaning files
    [Clockie.f3z]
2026-06-10 BOm
    added bom in readme file
